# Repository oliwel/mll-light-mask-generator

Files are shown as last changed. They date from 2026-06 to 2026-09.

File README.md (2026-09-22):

# MobaLedLib Lichtmasken-Generator

Dieser Generator erzeugt aus einer einfachen Text-Konfiguration eine druckfertige
3D-Lichtmaske (STL) für Modellgebäude. Die Maske wird von innen in das Gebäude
eingesetzt, trennt die Räume lichtdicht voneinander und nimmt die Hausplatine auf.

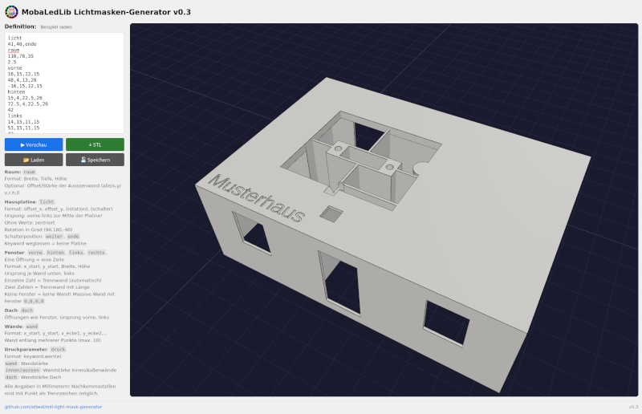
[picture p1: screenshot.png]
Screenshot des Generators


Diese Anleitung beschreibt **Schritt für Schritt, wie eine Konfiguration aufgebaut wird**.

---

## Bedienung in Kürze

1. Konfiguration in das Eingabefeld schreiben (oder eine vorhandene `.csv` laden).
2. **▶ Vorschau** klicken – das Modell erscheint rechts und lässt sich mit der Maus drehen.
3. Passt alles, mit **↓ STL** die Druckdatei speichern.

> **Tipp:** Fügt man Zellen aus einer Tabelle (z. B. Excel) ein, werden Tabulatoren
> automatisch in Kommas umgewandelt und die Vorschau startet von selbst.

---

## Vorbereitung

1. Stelle dein Modellhaus auf ein Blatt karriertes Papier und übertrage die
Aussenmaße auf das Papier.
2. Markiere alle Fenster und Türen durch einen dicken Strich auf der Wandlinie.
3. Messe für jedes Fenster den Abstand zur linken Hausecke und vom "Boden" sowie
   Breite und Höhe der Öffnung, schreibe die vier Zahlen an den Strich.
4. Bestimme den notwendigen Versatz der Maske nach Innen pro Wand, also um wieviel die gedruckte Maske kleiner sein muss als das Haus von außen.
5. Überlege dir die Position der Wände und skizziere Sie auf dem Papier
6. Finde eine geeignete Position für die Lichtplatine

---

## Grundregeln der Konfiguration

Eine Konfiguration besteht aus **Abschnitten**. Jeder Abschnitt beginnt mit einem
**Schlüsselwort** in einer eigenen Zeile, darunter folgen die zugehörigen **Datenzeilen**:

```
vorne
16,15,12.5,15
48,4,13,26
```

- Werte werden durch **Komma** getrennt.
- **Alle Maße in Millimetern.** Nachkommastellen mit Punkt schreiben (`2.5`, nicht `2,5`).
  Jeder einzelne Wert muss zwischen `-9999` und `9999` liegen.
- Die Reihenfolge der Abschnitte ist frei wählbar. Einzige Ausnahme: der
  Fenster-Abschnitt einer [benannten Wand](#fenster-in-einer-freien-wand) muss
  **nach** der `wand`-Zeile stehen, die den Namen vergibt.
- Mit `#` beginnt ein **Kommentar** – sowohl als ganze Zeile als auch am Zeilenende:

```
# Vorderseite
vorne
16,15,12.5,15 # Fenster Wohnzimmer
48,4,13,26  # Haustüre
```
### Koordinatensystem Grundkörper

Der Ursprung liegt in der **vorderen linken Ecke**. Von dort aus:

- **X** läuft nach **rechts** (= Breite),
- **Y** läuft nach **hinten** (= Tiefe)

### Koordinatensystem Fenster

Der Ursprung liegt in der **vorderen unteren Ecke** der Wand. Von dort aus:

- **X** läuft nach **rechts**,
- **Y** läuft nach **oben**

---

## Schritt 1 – Raumgröße und Offsets (`raum`)

Der `raum`-Abschnitt ist die Basis jeder Konfiguration.

**Erste Zeile – Außenmaße (Pflicht):** `Breite, Tiefe, Höhe`

```
raum
110,78,35
```

**Zweite Zeile – Offset (optional):** ein Versatz, um den die gedruckte Maske
gegenüber dem Raum nach innen verkleinert wird. Die Idee dahinter: Alle Maße
werden an der Außenseite des Hauses gemessen, der Generator rechnet automatisch
alle Positionen so um dass die Maske am Ende um den Versatz kleiner ist und
in das Haus geschoben werden kann.

> [!TIP] Die üblicherweise nach innen überstehender Fenster-/Türeinsätze oder
> Verstärkungen an den Kanten müssen beim Versatz mit berücksichtigt werden,
> sonst ist eure Maske nachher zu groß.

Je nach Anzahl der Werte:

| Werte | Bedeutung |
|---|---|
| `2.5` | gleicher Offset auf **allen vier Seiten** |
| `2.5,1` | wie die Maßzeile: erste Zahl = **Breite** (links & rechts), zweite = **Tiefe** (vorne & hinten) |
| `2,1,2,1` | je Seite einzeln: **vorne, rechts, hinten, links** |
| `2.5,1,45` | wie `2.5,1`, dazu die **Fussbodenhöhe** 45 (siehe unten) |
| `2,1,2,1,45` | wie `2,1,2,1`, dazu die **Fussbodenhöhe** 45 |

> [!CAUTION] Die Reihenfolge unterscheidet sich zwischen den beiden Formen. Mit
> **zwei** Werten zählt die Zeile **Achsen** wie die Maßzeile: `Breite, Tiefe`.
> Mit **vier** Werten zählt sie **Seiten** reihum ab vorne:
> `vorne, rechts, hinten, links`. Die vier Seiten einzeln zu setzen heißt also
> nicht, einfach zwei Werte anzuhängen – `2,1` entspricht `1,2,1,2`.

**Fussbodenhöhe (optional, letzter Wert):** bei einem mehrstöckigen Haus misst man
die Fensterhöhen bequemer **einmal durchgängig vom Erdboden** statt für jedes
Stockwerk neu. Die Fussbodenhöhe sagt dem Generator, wie hoch der Fussboden dieses
Stockwerks über dem Erdboden liegt; sie wird von jeder Höhenangabe einer Öffnung
abgezogen. Liegt der Fussboden des ersten Obergeschosses 45 mm über dem Erdboden,
wird aus einem bei 52 gemessenen Fenster eine Öffnung 7 mm über dem Boden der Maske.

Sie steht immer als **letzter** Wert hinter der Zwei- oder Vierwertform. An die
Einwertform lässt sie sich nicht anhängen – `2.5,45` wäre die Achsenform. Wer auf
allen Seiten denselben Versatz will, schreibt also `2.5,2.5,45`.

> [!NOTE] Die Fussbodenhöhe hat nichts mit der Stockwerkszeile `G<n>` zu tun. `G<n>`
> steuert Drehung, Gravur und Stapelecken, kennt aber keine Höhen – die Stockwerke
> dürfen unterschiedlich hoch sein. Beides wird getrennt angegeben.

```
raum
110,78,35
2.5
```

### Dritte Zeile – Stockwerk (`G<n>`), optional

Werden mehrere Räume übereinander gestapelt, bekommt der `raum`-Abschnitt eine
eigene Zeile `G<n>` mit der Stockwerksnummer (`G0` = Erdgeschoss, einstellig).
Sie gilt für den ganzen Raum und setzt automatisch:

- jedes **ungerade** Stockwerk dreht alle Platinen um 180°, damit die Anschlüsse
  abwechselnd liegen,
- die Ziffer wird in die **vordere rechte Ecke** des Dachs graviert, sodass am
  gedruckten Teil ablesbar ist, zu welchem Stockwerk es gehört,
- an den vier **Innenecken der Außenwände** kommt je eine Aussparung im Dach;
  ab `G1` sitzt an denselben Ecken unten ein passender Zapfen. Aufeinandergesetzt
  rasten die Räume darüber ineinander ein. An einer Ecke, an der beide
  angrenzenden Außenwände fehlen (Wand ohne Öffnungen), entfällt der Zapfen.

Die Ecken liegen **innen an den Wänden**, die Außenkontur der Maske bleibt also
unberührt und beim Einschieben ins Haus setzt nichts auf. Drei Ecken sind
Quadrate mit 2 mm Kantenlänge, die Ecke **vorne links** ist ein Viertelkreis mit
3 mm Radius – damit passen gestapelte Räume nur in einer Drehlage zusammen.

Die Offset-Zeile darf fehlen, `G<n>` steht dann direkt unter den Außenmaßen.

```
raum
110,78,35
2.5
G1
```

---

## Schritt 2 – Hausplatine platzieren (`licht`)

Der `licht`-Abschnitt bestimmt, wo die Platine sitzt. Die Platinenaufnahme hat ein
festes Format von **41 × 36 mm** und muss mit mindestens **2 mm** Abstand
vollständig innerhalb der Maske liegen.

**Format:** `Mitte-X, Mitte-Y [, Rotation] [, Schalter] [, Anschluss]`

- `Mitte-X, Mitte-Y` = Koordinaten des **Platinenmittelpunkts** (vom Ursprung vorne links).
- `Rotation` (optional) = Drehung in Grad: `90`, `180`, `-90`. Ohne Angabe setzt die Stockwerkszeile `G<n>` des `raum`-Abschnitts die Drehung.
- `Schalter` (optional) = Position des Schalterausschnitts: `weiter` oder `ende`.
- `Anschluss` (optional) = Schlüsselwort: `idc` druckt die IDC-Buchse mit, `stack` nur die Führung für die Platinenverbinder. Ohne Schlüsselwort bleibt der Tunnel offen.

Werden beide Schlüsselwörter angegeben, steht `Schalter` **vor** `Anschluss`:
`41,40,ende,idc` ist gültig, `41,40,idc,ende` nicht.

```
licht
41,40,ende,idc
```

Weitere Möglichkeiten:

- **Automatisch zentrieren:** Abschnitt `licht` ohne Werte (oder eine einzelne `0`)
  schreiben – die Platine wird mittig im Raum platziert.
- **Keine Platine:** den `licht`-Abschnitt komplett weglassen.

> [!INFO] Unter der Platine wird immer der Tunnel für den Anschluß und vier
> Wandstücke bis an den Dachausschnitt eingefügt.

---

## Schritt 3 – Fenster und Türen (`vorne`, `hinten`, `links`, `rechts`)

Für jede Außenwand gibt es einen eigenen Abschnitt. Jede **Öffnung** (Fenster oder
Tür) ist eine **eigene Zeile**.

**Format:** `Abstand, Höhe-über-Boden, Breite, Höhe`

- `Abstand` = horizontale Lage entlang der Wand, gemessen von der Ecke.
- `Höhe-über-Boden` = Abstand der **Unterkante** vom Boden. Ist in der Offset-Zeile
  eine Fussbodenhöhe gesetzt, wird ab **Erdboden** gemessen statt ab dem Fussboden
  dieses Stockwerks.
- `Breite, Höhe` = Größe der Öffnung.

Der Ursprung jeder Wand liegt **unten links** (von außen betrachtet). Ein **negativer
Abstand** misst von der **gegenüberliegenden Ecke** – praktisch für Öffnungen, die
rechts bündig sitzen sollen.

```
vorne
16,15,12,15
48,4,13,26
-16,15,12,15
```

> [!CAUTION] Eine Wand ohne Einträge wird **gar nicht gedruckt**. Soll eine Wand
> massiv (geschlossen, ohne Fenster) sein, trägt man eine „Null-Öffnung“ ein: `0,0,0,0`.

---

## Schritt 4 – Automatikwände (Trennwände)

In denselben Wandabschnitten (`vorne`, `hinten`, `links`, `rechts`) lassen sich
**innere Trennwände** definieren, indem statt vier Werten nur **eine oder zwei Zahlen**
in der Zeile stehen:

- **Eine Zahl** → automatische Trennwand: Die Zahl ist die **Position** entlang der
  Wand. Die Trennwand wächst von der Außenwand nach innen bis zum Dachausschnitt
  der Platine. Die Lücke zwischen der Wand und der Stützwand der Platine wird
  entlang der Dachkante automatisch geschlossen. Sind mehrere Platinen definiert,
  läuft die Wand zu der Platine, deren Mitte ihrem Ansatzpunkt an der Außenwand
  am nächsten liegt.
- **Zwei Zahlen** (`Position, Länge`) → Trennwand mit **fester Länge**, es
  findet keine automatische Verbindung mit der Stützstruktur statt.

```
hinten
15,4,22.5,26     # Fenster (4 Werte)
72.5,4,22.5,26   # Fenster (4 Werte)
42               # automatische Trennwand bei Position 42
```

Ein negativer Positionswert misst wieder von der gegenüberliegenden Ecke.

---

## Schritt 5 –  Freie Wände (`wand`)

Für Innenwände, die nicht an einer Außenwand beginnen, gibt es den `wand`-Abschnitt.
Eine Zeile beschreibt einen **Linienzug** aus Eckpunkten – die Wand verläuft von Punkt
zu Punkt.

**Format:** `x1, y1, x2, y2 [, x3, y3, …]` (mindestens 2 Punkte, nach oben offen)

Ein `wand`-Abschnitt nimmt beliebig viele solcher Zeilen auf; jede ist eine
**eigenständige** Wand.

```
wand
41,0,41,25,66,25,66,0    # ein Linienzug über drei Segmente
27,0,27,22               # davon unabhängige zweite Wand
```

**Linienzug über mehrere Zeilen:** Trägt eine Zeile nur **ein** Koordinatenpaar,
verlängert sie die zuletzt begonnene Wand um diesen Punkt – unabhängig davon, wie
viele Punkte deren vorige Zeile hatte. Eine Zeile mit **zwei oder mehr** Paaren
beginnt dagegen immer eine neue Wand.

```
wand
10,10               # ┐
20,20               # ├ eine Wand über zwei Segmente
30,30               # ┘
40,40,50,50         # neue Wand …
60,20               # … um einen Punkt verlängert
```

> [!CAUTION] Ein einzelnes Koordinatenpaar, das nichts fortsetzt und selbst nicht
> fortgesetzt wird, ergibt kein Segment und wird als Fehler gemeldet.

Auch hier messen negative Koordinaten von der rechten bzw. hinteren Raumkante.
Die Wände können anhand der Außenmaße gesetzt werden, der Generator beschneidet
die Länge automatisch an der Außenhülle der Maske.

### Fenster in einer freien Wand

Ein einzelnes **gerades** Segment eines Linienzugs lässt sich benennen und bekommt
dann eigene Fenster – wie eine Außenwand. Der Name ist ein beliebiges Wort, das
hinter dem **Startpunkt** des Segments steht; das Segment endet am nächsten Punkt.

**Format:** `x1, y1, name, x2, y2` – oder zweizeilig, mit dem Endpunkt in der Folgezeile:

```
wand
20,10,flur
20,50
```

Der Name wird anschließend zum **Abschnitts-Schlüsselwort** für die Öffnungen. Sie
werden wie bei den Außenwänden angegeben, der `Abstand` misst dabei ab dem
Startpunkt der Wand (`x1, y1`):

```
flur
5,0,8,12
25,4,6,8
```

- Der Name darf kein reserviertes Schlüsselwort sein (`raum`, `wand`, `vorne`, …)
  und nicht zweimal vergeben werden.
- Der Fenster-Abschnitt muss **nach** der `wand`-Zeile stehen, die den Namen
  vergibt – sonst ist der Name noch unbekannt und die Datei wird abgewiesen.
- Benannt wird immer nur **ein** Segment, nicht der ganze Linienzug. Ein Linienzug
  kann mehrere benannte Segmente enthalten.
- Ohne zugehörigen Fenster-Abschnitt bleibt das Segment eine normale freie Wand.
- Anders als bei den Außenwänden ist der `Abstand` hier immer positiv; negative
  Werte werden nicht von der Gegenecke gemessen, sondern abgewiesen.

---

##  Optional – Beschriftung (`text`)

Beschriftet die Oberseite der Maske, z. B. mit dem Hausnamen (max. 50 Zeichen).

**Format (je nach Detailgrad):**

| Zeile | Bedeutung |
|---|---|
| `Musterhaus` | Text, automatisch platziert: 3 mm/3 mm von der vorderen linken Ecke des **Druckkörpers**, wandert also mit dem Offset |
| `20,30,Musterhaus` | Text an Position `X,Y` |
| `20,30,90,Musterhaus` | Text an Position `X,Y` mit Drehung in Grad |

```
text
Musterhaus
```

Zwei Einschränkungen ergeben sich aus dem CSV-Format: Der Text darf **kein Komma**
enthalten (es trennt die Felder), und er darf nicht genauso heißen wie ein
Abschnitts-Schlüsselwort oder eine benannte Wand – ein solches Wort beendet den
`text`-Abschnitt, statt als Beschriftung zu gelten.

---

## Optional – Dachöffnungen (`dach`)

Zusätzliche Öffnungen in der Dachfläche, z. B. für Dachfenster oder zum Einbau weiterer LEDs von oben.

**Format:**
- `X, Y, Breite, Tiefe` – rechteckiger Ausschnitt (Ecke bei X,Y, Ursprung vorne links)
- `X, Y, <LED-Typ>` – Öffnung passend zu einem LED-Typ (Mitte bei X,Y); die Geometrie
  wird wie in der Lichtbox erzeugt. Anstelle der Ausschnitt-Masse wird der Name des
  LED-Typs angegeben: `none` (auch `keine`), `3mm`, `5mm`, `plcc6`, `plcc2`, `ws2812`.

```
dach
44,10,5,5
55,40,ws2812
```

---

## Optional – Druckparameter (`druck`)

Feineinstellung der Wandstärken. Jede Zeile: `Schlüssel, Wert`.

| Schlüssel | Bedeutung | Standard |
|---|---|---|
| `wand` | allgemeine Wandstärke | 0.8 mm |
| `aussen` | Stärke der Außenwände | wie `wand` |
| `innen` | Stärke der Innenwände | wie `wand` |
| `dach` | Stärke der Dachfläche | 1.0 mm |

```
druck
aussen,1.0
dach,1.2
```

---

## Lichtbox-Modus (`box`)

Statt einer kompletten Hausmaske (`raum`) lässt sich auch eine einzelne **Lichtbox**
erzeugen – ein kleiner Kasten, der über eine LED gestülpt wird und das Licht
gerichtet abgibt. Sobald das Schlüsselwort `box` in der Konfiguration vorkommt,
schaltet der Generator auf den Lichtbox-Renderer (`lightbox.scad`) um; `box` und
`raum` schließen sich gegenseitig aus.

**Erste Zeile – Außenmaße (Pflicht):** `Breite, Höhe, Tiefe`

```
box
40,25,15
```

### LED-Öffnungen (`oben`, `links`, `rechts`)

Die Schlüsselwörter `oben`, `links` und `rechts` setzen je eine (oder mehrere)
LED-Öffnung auf die entsprechende Fläche. Jede Öffnung ist eine eigene Zeile, die
mit dem **LED-Typ** beginnt:

| LED-Typ | Bedeutung |
|---|---|
| `none` (auch `keine`) | keine Öffnung |
| `3mm` | durchgehende Bohrung 3 mm |
| `5mm` | durchgehende Bohrung 5 mm |
| `plcc6` | PLCC6 (innen 4 mm, außen 6×6 mm) |
| `plcc2` | PLCC2 (innen 3 mm, außen 4×3 mm) |
| `ws2812` | innen 6×6 mm, außen 15 mm |

**Format:** `<typ> [, <clip>] [, offset_breite [, offset_tiefe]]`

- Nur `<typ>` → LED **mittig** auf der Fläche.
- `<clip>` (optional, 2. Argument) → Halteclip: `ohne`, `einfach` oder `doppel`.
  Standard ist `ohne` und kann weggelassen werden.
- `offset_breite` → Verschiebung **entlang der Vorderkante** der Fläche.
- `offset_tiefe` → zusätzliche Verschiebung **in Tiefenrichtung (Z)**.

Die Offsets messen von der **Flächenmitte** aus und dürfen der Kante nicht näher
als **5 mm** kommen.

```
box
40,25,15
oben
plcc6, doppel
links
ws2812, 4
rechts
plcc2, einfach, 4, -2
```

---

## Vollständiges Beispiel

```
licht
41,40,ende,idc
raum
110,78,35
2.5
vorne
16,15,12,15
48,4,13,26
-16,15,12,15
hinten
15,4,22.5,26
72.5,4,22.5,26
42
links
14,15,11,15
53,15,11,15
42
rechts
14,15,11,15
53,15,11,15
42
wand
41,0,41,25,66,25,66,0
dach
44,10,5,5
text
Musterhaus
```

---

## Anhang – Generator starten

Der Generator ist ein kleiner Webserver, der OpenSCAD zum Rendern aufruft. Beides
muss lokal installiert sein.

```
python3 server.py
```

Danach ist die Oberfläche unter **http://localhost:8080** erreichbar. Sie lädt die
Vorschau über `POST /preview` und liefert die Downloads über `POST /` (STL) und
`POST /export3mf` (3MF).

Ohne Oberfläche lässt sich eine Konfiguration auch direkt übersetzen – die Ausgabe
ist das Datenfile, das `house_mask.scad` einliest:

```
python3 server.py --parse meine_maske.csv > house_data.scad
```

Mit `--debug` schreibt der Server zusätzlich das Datenfile jeder Anfrage auf die
Konsole – hilfreich, um nachzusehen, was aus einer Konfiguration tatsächlich
geworden ist.

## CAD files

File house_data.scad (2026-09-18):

room_width   = 110;
room_depth   = 78;
room_height  = 35;
licht_w      = 41;
licht_d      = 36;
wand         = 0.8;
aussenwand   = 0.8;
innenwand    = 0.8;
dachwand     = 1.0;
poly_walls   = [[[41.0,2.5], [41.0,25.0]], [[41.0,25.0], [66.0,25.0]], [[66.0,25.0], [66.0,2.5]]];
named_walls  = [];
print_offset = [2.5, 2.5, 2.5, 2.5];
front_windows = [[16,15,12,15], [48,4,13,26], [82,15,12,15]];
back_windows  = [[15,4,22.5,26], [72.5,4,22.5,26]];
left_windows  = [[14,15,11,15], [53,15,11,15]];
right_windows = [[14,15,11,15], [53,15,11,15]];
geschoss = -1;
licht = [[41,40,0,2,2]];
dach_cuts = [[50,10,4]];
front_walls = [];
back_walls  = [[68,-1]];
left_walls  = [[36,-1]];
right_walls = [[42,-1]];
texts = [["Musterhaus", 4.5, 4.5, 0]];

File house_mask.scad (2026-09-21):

// Hausmaske mit Fenster- und Türöffnungen aus CSV-Daten
// Aufruf: python3 server.py --parse sample.csv > house_data.scad
// Dann diese Datei in OpenSCAD öffnen.

include <house_data.scad>

// ── Konstanten ────────────────────────────────────────────────────────────────
licht_h = 1.2; // Einstecktiefe Lichtausschnitt von Dachoberkante [mm]
tunnel_w   = 15;   // Tunnel Innenbreite (X) [mm]
tunnel_d   = 9;    // Tunnel Innentiefe  (Y) [mm]
tunnel_wall = 1.2; // Tunnel Wandstärke

// ── LED-Öffnungen im Dach (portiert aus lightbox.scad) ──────────────────────────
// Öffnungstyp (dach_cuts-Eintrag [cx, cy, led]). Bestimmt die komplette
// Öffnungsgeometrie; wird anstelle der Ausschnitt-Masse (breite,tiefe) übergeben.
// Zweiteilige Öffnungen sind durchgehend: das größere Feature (LED-Tasche) sitzt auf
// der Dachoberseite, das kleine Feature (Lichtaustritt) liegt led_membrane (0.4mm)
// tief auf der Rauminnenseite (Platzierung dreht die kanonische Lage um 180°).
LED_NONE   = 0; // keine Öffnung
LED_3MM    = 1; // durchgehender Zylinder 3mm
LED_5MM    = 2; // durchgehender Zylinder 5mm
LED_5050   = 3; // Licht Zylinder 4mm, Tasche 6x6mm
LED_3528   = 4; // Licht Zylinder 3mm, Tasche 4x3mm
LED_WS2812 = 5; // Licht Ausschnitt 6x6mm, Tasche Zylinder 11mm

led_membrane = 0.4; // verbleibende Materialdicke auf der Lichtaustrittsseite [mm]

/*
 * Einzelnes Feature einer Öffnung, zentriert um z = 0, Höhe h.
 *   shape als Vektor [x,y]  -> quadratischer Ausschnitt
 *   shape als Zahl d        -> Zylinder mit Durchmesser d
 */
module led_feature( shape, h ) {
    if (is_list(shape))
        cube([shape[0], shape[1], h], true);
    else
        cylinder(d = shape, h = h, center = true, $fn = 48);
}

/*
 * Negativform der LED-Öffnung in kanonischer Lage:
 *   Wandmitte liegt bei z = 0, die Wand (Dicke wall) reicht von -wall/2 bis +wall/2;
 *   +z zeigt zur Lichtaustrittsseite (Dachoberseite).
 *   through  = durchgehender Zylinder (Durchmesser) über die ganze Dachdicke
 *   inner    = kleines Feature an der Lichtaustrittsseite, led_membrane (0.4mm) tief
 *   outer    = LED-Tasche auf der Rauminnenseite, restliche Dachdicke
 */
module led_negative( wall, inner = undef, outer = undef, through = undef ) {
    eps = 0.1 * wall; // Überstand gegen Rendering-Fehler an den Flächen
    if (!is_undef(through))
        cylinder(d = through, h = wall + 2*eps, center = true, $fn = 48);
    if (!is_undef(inner))
        translate([0, 0, (wall - led_membrane + eps)/2])
            led_feature(inner, led_membrane + eps);
    if (!is_undef(outer))
        translate([0, 0, -led_membrane/2])
            led_feature(outer, wall - led_membrane + 2*eps);
}

/*
 * Negativform der LED-Öffnung nach Öffnungstyp (kanonische Lage, +z = Oberseite).
 * wall = Dachdicke.
 */
module led_negative_by_type( led, wall ) {
    if (led == LED_3MM)         led_negative(wall, through = 3);
    else if (led == LED_5MM)    led_negative(wall, through = 5);
    else if (led == LED_5050)   led_negative(wall, inner = 4,     outer = [6,6]);
    else if (led == LED_3528)   led_negative(wall, inner = 3,     outer = [4,3]);
    else if (led == LED_WS2812) led_negative(wall, inner = [6,6], outer = 11);
}


// ── 6-polige IDC-Buchse (2×3, 2,54 mm Raster) ───────────────────────────────────
// Aufnahmetasche für eine weibliche IDC-Pfostenbuchse (Flachbandkabel-Stecker,
// FC-6P). Die Tasche öffnet nach z = 0, sitzt im rechten Tunnelabschnitt und ist
// so gesetzt, dass die linke Kontaktspalte auf der Mittelachse des Dachausschnitts
// liegt; dafür wird die Tunnelwand rechts um idc_ext verbreitert. Diese linke
// Spalte wird nicht kontaktiert und bleibt daher geschlossen.
// Der Sockel füllt den Tunnelquerschnitt vom Tunnelboden bis zur Oberkante der
// Grundplatte.
//   Lokales System: Ursprung = Tunnelmitte in X/Y, z = 0 am Tunnelboden.
//
// Anschlussart (licht-Eintrag l[4]):
IDC_NONE  = 0; // kein Anschluss im Tunnel
IDC_PLUG  = 1; // Buchse mit Steckertasche für das Flachbandkabel
IDC_STACK = 2; // nur die Grundplatte als Führung für die Platinenverbinder;
               // ohne Steckertasche, damit gestapelte Räume aufeinander passen
idc_pitch = 2.54; // Rastermaß IDC [mm]
idc_cols  = 3;    // Kontakte in X
idc_rows  = 2;    // Kontakte in Y
idc_in_w  = 12.4; // Innenmaß der Tasche in X, lt. Standard 12.19 [mm]
idc_in_d  = 7;    // Innenmaß der Tasche in Y, lt. Standard 6.8 [mm]
idc_gap   = 6;    // Oberkante der Grundplatte über dem Tunnelboden [mm]
idc_base  = 1;  // Dicke der Grundplatte mit den Kontaktlöchern [mm]
idc_hole  = 1.4;  // Öffnung je Kontaktkammer [mm]

// Taschenmitte rechts der Mittelachse: die Kontakte sind in der Tasche zentriert,
// die linke Kontaktreihe liegt auf x = 0.
idc_off_x = (idc_cols - 1)/2 * idc_pitch;
// Verbreiterung der rechten Tunnelwand, damit die Tasche eine volle Wandstärke
// behält. Gilt über die gesamte Tunnelhöhe, sonst entstünde eine Auskragung.
idc_ext   = max(0, idc_off_x + idc_in_w/2 + tunnel_wall - (tunnel_w/2 + tunnel_wall));

// Oberkante der Grundplatte: die Buchse braucht darunter die Steckertasche, die
// Führung besteht nur aus der Grundplatte selbst.
function idc_base_z(idc_mode) = idc_mode == IDC_STACK ? idc_base : idc_gap;
// Verbreiterung nur für die Steckertasche; die Führung bleibt im Tunnelquerschnitt,
// damit gestapelte Räume dieselbe Außenkontur behalten.
function idc_mode_ext(idc_mode) = idc_mode == IDC_STACK ? 0 : idc_ext;

// Positivteil: Sockel bis zur Grundplatten-Oberkante plus Fase darüber.
module idc_socket_body(idc_mode, wall = tunnel_wall) {
    eps    = 0.01;                 // Überlappung der beiden Fasenhälften
    base_z = idc_base_z(idc_mode); // Oberkante der Grundplatte
    ramp   = tunnel_d/2;           // 45°-Fase von der Tunnelwand bis zur Mitte
    body_w = tunnel_w + 2*wall + idc_mode_ext(idc_mode);

    translate([-(tunnel_w/2 + wall), 0, 0]) {
        // Sockel über den gesamten Tunnelquerschnitt
        translate([0, -(tunnel_d/2 + wall), 0])
            cube([body_w, tunnel_d + 2*wall, base_z]);

        // Fase als Stützstruktur über der Grundplatte, aufgespannt zwischen den
        // Tunnel-Längswänden bei y = ±ramp. Beim Druck liegt die Dachfläche
        // unten, +z zeigt also nach unten: die Grundplatte wäre sonst eine frei
        // hängende Fläche. Beide Hälften setzen an den Wänden an und wachsen
        // unter 45° bis zur Mitte zusammen, sodass jede Schicht nur um eine
        // Schichthöhe auskragt. Die Fase läuft über die gesamte Tunnelbreite.
        for (s = [-1, 1])
            rotate([90, 0, 90])
                linear_extrude(height = body_w)
                    polygon([[-s * eps,  base_z],
                             [s * ramp,  base_z],
                             [s * ramp,  base_z + ramp]]);
    }
}

// Negativteil: Steckertasche, Kodiernase und Kontaktkammern. Die Führung
// (IDC_STACK) hat keine Tasche, die Grundplatte liegt dort direkt am Tunnelboden.
module idc_socket_cavity(tunnel_h, idc_mode, wall = tunnel_wall) {
    pocket_z = idc_base_z(idc_mode) - idc_base; // Taschendecke = Unterseite Grundplatte

    if (idc_mode != IDC_STACK) {
        // Steckertasche, nach z = 0 offen
        translate([idc_off_x, 0, pocket_z/2 - 0.05])
            cube([idc_in_w, idc_in_d, pocket_z + 0.1], true);

        // Kodiernase des Steckers in der Vorderwand
        translate([idc_off_x, -idc_in_d/2 - wall/2, pocket_z/2 - 0.05])
            cube([4, wall + 0.1, pocket_z + 0.1], true);
    }

    // Kontaktkammern durch Grundplatte und Fase bis über die Tunneloberkante,
    // damit die Kontakte frei liegen. Die linke Spalte auf der Mittelachse wird
    // nicht kontaktiert und entfällt in beiden Betriebsarten.
    for (ix = [1 : idc_cols - 1], iy = [0 : idc_rows - 1])
        translate([ix * idc_pitch,
                   (iy - (idc_rows - 1)/2) * idc_pitch,
                   (pocket_z + tunnel_h)/2])
            cube([idc_hole, idc_hole, tunnel_h - pocket_z + 0.2], true);
}

// ── Print-Offset ──────────────────────────────────────────────────────────────
// print_offset = [vorne, rechts, hinten, links]
po_fr = print_offset[0];   // Vorderwand-Versatz
po_ri = print_offset[1];   // Rechte-Wand-Versatz
po_ba = print_offset[2];   // Hinterwand-Versatz
po_le = print_offset[3];   // Linke-Wand-Versatz

// Innenflächen der Außenwände (virtuelle Koordinaten)
wall_front_inner = po_fr + aussenwand;
wall_back_inner  = room_depth  - po_ba - aussenwand;
wall_left_inner  = po_le + aussenwand;
wall_right_inner = room_width  - po_ri - aussenwand;

// ── Lichtöffnung ──────────────────────────────────────────────────────────────
// licht = [[cx, cy, rotation, slot_mode, idc], ...]
// cx/cy = Mittelpunkt des Ausschnitts, absolute SCAD-Koordinaten vom Körperursprung (0,0).
// Ohne Datenwerte im licht-Abschnitt → automatisch zentriert (server.py).
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

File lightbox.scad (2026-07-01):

/* Konstanten für Kastenformat */
OPEN_NONE = 0; // Box mit fünf Seiten
OPEN_LEFT = -1; // Box mit vier Seite, vorne und links offen
OPEN_RIGHT = 1; // Box mit vier Seite, vorne und rechts offen

/*
 * LED-Öffnungstyp (Parameter "led"). Bestimmt die komplette Öffnungsgeometrie.
 * Zweiteilige Öffnungen sitzen auf der Rückwand und sind durchgehend: das innere
 * Feature (LED-/Lichtseite) ist led_membrane (0.4mm) tief, das äußere Feature
 * nimmt die restliche Wanddicke ein.
 */
LED_NONE   = 0; // keine Öffnung
LED_3MM    = 1; // durchgehender Zylinder 3mm
LED_5MM    = 2; // durchgehender Zylinder 5mm
LED_5050   = 3; // innen Zylinder 4mm, außen Ausschnitt 6x6mm (WS2812)
LED_3528   = 4; // innen Zylinder 3mm, außen Ausschnitt 4x3mm
LED_WS2812 = 5; // innen Ausschnitt 6x6mm, außen Zylinder 15mm
LED_DEFAULT = LED_5050;

/*
 * Halteclip auf der Deckenwand (Parameter "clip"), unabhängig vom Öffnungstyp.
 */
CLIP_NONE   = 0; // kein Clip
CLIP_SINGLE = 1; // ein Clip mittig über der Öffnung
CLIP_DOUBLE = 2; // zwei Clips, 14mm Abstand (je 7mm links/rechts der Mitte)
clip_dist   = 12; // Abstand der beiden Clips bei CLIP_DOUBLE

/*
 * Fläche, auf der LED-Öffnung + Clip sitzen (Parameter "face").
 * Die LED-Position wird als [u, v] relativ zur Flächenmitte (mm) angegeben:
 *   FACE_TOP:   u entlang Breite (X), v entlang Tiefe (Z)
 *   FACE_LEFT/RIGHT: u entlang Tiefe (Z), v entlang Höhe (Y)
 * u ist zugleich die Achse, entlang der die Doppelclips versetzt werden.
 */
FACE_TOP   = 0; // oben:   X-Z-Fläche bei y = +height/2 (größere Y-Koordinate)
FACE_LEFT  = 1; // links:  Y-Z-Fläche bei x = -width/2
FACE_RIGHT = 2; // rechts: Y-Z-Fläche bei x = +width/2

/* Wandstärke */
wall = 1.2;
tunnel_height = 2;
clip_spacing = 3;
clip_thick = 2.5;
/* verbleibende Materialdicke auf der Innenseite bei quadratischem Ausschnitt */
led_membrane = 0.4;
/*
 * width/height = Abmessungen des "Fensters" (Außenmass)
 * depth = Tiefe der Kiste
 * open = Kiste mit zwei offenen Seiten für Über-Eck Einbau
 * led = Öffnungstyp (LED_*), siehe Konstanten oben
 * led_offset = Abweichung der LED Position von der Mitte
 *    Zahl > 1: Offset in Einheiten von der Mitte aus
 *    Zahl < 1: relative Position auf der Wand von links außen gemessen
*/
/*
 * Einzelnes Feature einer Öffnung, zentriert um z = 0, Höhe h.
 *   shape als Vektor [x,y]  -> quadratischer Ausschnitt
 *   shape als Zahl d        -> Zylinder mit Durchmesser d
 */
module led_feature( shape, h ) {
    if (is_list(shape))
        cube([shape[0], shape[1], h], true);
    else
        cylinder(d = shape, h = h, center = true, $fn = 48);
}

/*
 * Negativform der LED-Öffnung in kanonischer Lage:
 *   Wandmitte liegt bei z = 0, die Wand reicht von -wall/2 (außen) bis
 *   +wall/2 (innen); +z zeigt ins Innere der Box.
 *   through  = durchgehender Zylinder (Durchmesser) über die ganze Wand
 *   inner    = Feature auf der Innenseite, led_membrane (0.4mm) tief
 *   outer    = Feature auf der Außenseite, restliche Wanddicke
 *   inner und outer überlappen in der Wand -> durchgehende Öffnung.
 */
module led_negative( inner = undef, outer = undef, through = undef ) {
    eps = 0.1 * wall; // Überstand gegen Rendering-Fehler an den Flächen
    if (!is_undef(through))
        cylinder(d = through, h = wall + 2*eps, center = true, $fn = 48);
    if (!is_undef(inner))
        translate([0, 0, (wall - led_membrane + eps)/2])
            led_feature(inner, led_membrane + eps);
    if (!is_undef(outer))
        translate([0, 0, -led_membrane/2])
            led_feature(outer, wall - led_membrane + 2*eps);
}

/*
 * Negativform der LED-Öffnung nach Öffnungstyp (kanonische Lage, +z = innen).
 */
module led_negative_by_type( led, dist_ground ) {
    if (led == LED_3MM)         led_negative(through = 3);
    else if (led == LED_5MM)    led_negative(through = 5);
    else if (led == LED_5050)   led_negative(inner = 4,      outer = [6,6]);
    else if (led == LED_3528)   led_negative(inner = 3,      outer = [4,3]);
    else if (led == LED_WS2812) {
        led_negative(inner = [6,6],  outer = 11);
        translate([0, -5.5, -led_membrane/2]) cube([6, dist_ground, 1.1 * wall - led_membrane ],true);
    }
}

/*
 * Setzt die Kinder in kanonischer Lage auf die gewählte Fläche der Box:
 *   - Wandmitte der Fläche liegt im Ursprung der Kinder
 *   - kanonisches +z zeigt ins Box-Innere
 * pos = [u, v] verschiebt entlang der Flächenachsen (siehe FACE_* oben).
 */
module on_face( face, pos, width, height, depth ) {
    if (face == FACE_TOP)
        translate([pos[0], height/2 - wall/2, pos[1]]) rotate([90,0,0]) children();
    else if (face == FACE_RIGHT)
        translate([width/2 - wall/2, pos[1], pos[0]]) rotate([0,-90,0]) rotate([0,0,-90]) children();
    else if (face == FACE_LEFT)
        translate([-width/2 + wall/2, pos[1], pos[0]]) rotate([0,90,0]) rotate([0,0,90]) children();
}

/*
 * Halteclip, IMMER entlang Z (Tiefe) ausgerichtet, unabhängig von der Fläche.
 * Lokaler Aufbau: Außenfläche der Wand bei y = 0, Clip ragt nach +y (außen),
 * Balken läuft über die ganze Tiefe in Z.
 *   - Verbindung zum Gehäuse an der oberen Kante (z = +depth/2).
 *   - 3x3mm Pod am unteren Ende (z = -depth/2, Druckbett) als Haftungshilfe.
 */
module clip_z( depth ) {
    bar_y  = clip_spacing + clip_thick/2; // Mitte des Haltebalkens (außen)
    pod_h  = 0.2;                          // Höhe des Druck-Pods
    color([1,0,0]) {
        // Haltebalken parallel zur Wand, über die ganze Tiefe
        translate([0, bar_y, 0]) cube([3, clip_thick, depth], true);
        // Verbindung zum Gehäuse an der oberen Kante (z = +depth/2)
        translate([0, 0, depth/2])
            rotate([-90, 0, 0])
                linear_extrude(height = clip_spacing+clip_thick)
                    polygon([[4, 0], [-4,0], [-1.5, 4], [1.5, 4]]);
        // Pod auf dem Druckbett (z = -depth/2), 3x3mm, verbessert die Haftung
        translate([0, bar_y + clip_thick/2, -depth/2 + pod_h/2])
            cube([5, 5, pod_h], true);
    }
}

/*
 * Setzt einen Clip auf die Außenseite der gewählten Fläche.
 *   perp = Versatz entlang der flächeninternen Achse senkrecht zu Z
 *          (X bei FACE_TOP, Y bei FACE_LEFT/RIGHT).
 * Der Balken läuft stets entlang Z, der Fuß bleibt in der Rückseiten-Ebene.
 */
module clip_on( face, perp, width, height, depth ) {
    if (face == FACE_TOP)
        translate([perp, height/2, 0]) clip_z(depth);
    else if (face == FACE_RIGHT)
        translate([width/2, perp, 0]) rotate([0,0,-90]) clip_z(depth);
    else if (face == FACE_LEFT)
        translate([-width/2, perp, 0]) rotate([0,0,90]) clip_z(depth);
}

/*
 * Box-Körper: Außenquader mit ausgehöhltem Innenraum (vorne offen). Bei
 * open != OPEN_NONE wird zusätzlich eine Seitenwand entfernt (Über-Eck Einbau).
 */
module lightbox_body( width, height, depth, open = OPEN_NONE ) {
    shrink = (open != OPEN_NONE ? wall : (2*wall));
    move = open * wall;
    difference(){
        cube([width,height,depth],true);
        translate([move,0,wall]) cube([width-shrink,height-2*wall,depth],true);
    }
}

/*
 * Box-Körper mit beliebig vielen LED-Öffnungen + Clips. leds ist eine Liste von
 * Einträgen [face, led, u, v, clip]:
 *   face = FACE_TOP | FACE_LEFT | FACE_RIGHT
 *   led  = LED_* Öffnungstyp
 *   u, v = LED-Mitte relativ zur Flächenmitte (mm), siehe on_face / FACE_*
 *   clip = CLIP_NONE | CLIP_SINGLE | CLIP_DOUBLE
 */
module lightbox_multi( width, height, depth, open = OPEN_NONE, leds = [] ) {
    translate([0,0,depth/2])
    union() {
        difference() {
            lightbox_body(width, height, depth, open);
            for (m = leds)
                on_face(m[0], [m[2], m[3]], width, height, depth)
                    led_negative_by_type(m[1], depth/2 - m[2]);
        }
        for (m = leds) {
            face = m[0];
            clip = m[4];
            // Clip-Versatz entlang der Achse senkrecht zu Z (= LED-Achse):
            // X bei FACE_TOP (u), Y bei FACE_LEFT/RIGHT (v).
            clip_perp = (face == FACE_TOP) ? m[2] : m[3];
            if (clip == CLIP_SINGLE)
                clip_on(face, clip_perp, width, height, depth);
            else if (clip == CLIP_DOUBLE)
                for (s = [-1, 1])
                    clip_on(face, clip_perp + s*clip_dist/2, width, height, depth);
        }
    }
}

module lightbox( width = 20, height = 25, depth = 15, open = OPEN_NONE, led = LED_DEFAULT, led_pos = [0,0], clip = CLIP_NONE, face = FACE_TOP ) {
    lightbox_multi(width, height, depth, open, [[face, led, led_pos[0], led_pos[1], clip]]);
}


module clibox() {
    width = 20;
    height = 15;
    depth = 20;
    open = OPEN_NONE;
    led = LED_WS2812;
    led_pos = [0,0];
    clip = CLIP_DOUBLE;
    face = FACE_TOP;

    lightbox( width = width, height = height, depth = depth, open = open, led = led, led_pos = led_pos, clip = clip, face = face );
}
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

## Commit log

2026-06-07 Initial Version
    [house_data.scad, house_mask.scad, sample.csv]
2026-06-10 Improve board, add text
    Resize board cut to 41x36
    Add setter for mode switch
    Add alignment nose
    Add engraved text
    [house_mask.scad, sample.csv]
2026-06-13 Fix coordinates for wand segments (relative)
    [house_mask.scad]
2026-06-15 Improve autopos of board / change ref to board center
    [house_mask.scad, sample.csv]
2026-06-15 Create each wall seperate
    Fixes problem of short walls/roof when not printing walls
    [house_mask.scad]
2026-06-23 Improvements / README
    Enhance light and colors for better contrast in viewer
    Generate STL upside down -> roof is on the printer bed
    README with step-by-step documentation to generate coordinates
    Paste handler to support "copy from excel" (tab as separator)
    Allow #inline comment
    [house_mask.scad]
2026-06-28 Rework mode switch to improve rendering
    [house_data.scad, house_mask.scad]
2026-06-28 Draft lightbox
    [lightbox.scad]
2026-06-29 Update index.html
    Anpassung Höhe des gesamten Fensters und Links im Footer hinzugefügt
2026-06-30 Rename ws2811 -> ws2812 in lightbox keywords
    [lightbox.scad]
2026-07-01 Improve WS2812 in lightbox
    Add tunnel to slide LED
    [lightbox.scad]
2026-07-01 Support LED types in dach section
    [house_mask.scad, sample.csv]
2026-07-01 Help Icon, 1mm grid, 3mf export
2026-07-01 Add help and sample for box mode
    [sample.csv]
2026-07-05 Consolidate wall generation into a single call
    [house_mask.scad]
2026-07-05 Consolidate inner wall generation into a single call
    [house_mask.scad]
2026-09-16 Support "named walls" / windows in user defined walls
    [house_mask.scad]
2026-09-16 Add connectors / improve stacking
    Print IDC connector holes
    Auto-rotate board when stacking
    Add pins and holes for stacking
    [house_data.scad, house_mask.scad, sample.csv]
2026-09-16 Autoroute wall to nearest light board
    [house_mask.scad]
2026-09-18 Fix polywalls, improve stacking, improve offsets
    [house_data.scad, house_mask.scad, sample.csv]
2026-09-21 Fixes for IDC connector / text alignment
    [house_mask.scad, sample.csv]
2026-09-22 Add first data samples for CSV
    [G0.csv, G1.csv, G2.csv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]
2026-11-01 Add export parameter, color 3MF preview, UI rework (v0.7)
    - Stacking corners: triangles (4 mm) in three corners, quarter circle
    (3 mm) at front left
    - Remove "maske" from the CSV; the export format (kompakt, beide,
    aussen, innen) is now the OpenSCAD parameter "export" with a selector
    in the UI; "beide" lays out the parts along the longer room edge
    - Print parameters: drop "wand", walls at least 0.8 mm, roof at least
    licht_h
    - Preview is a colored 3MF (ThreeMFLoader); STL and 3MF downloads are
    rendered by the server, file name from house name and floor
    - Serve three.js locally from static/ (make target "static")
    - UI: action line with icons, scrollable help with draggable splitter,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
